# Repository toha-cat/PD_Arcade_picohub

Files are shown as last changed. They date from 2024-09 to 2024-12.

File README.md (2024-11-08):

# PD Arcade picohub
=================================

Firmware for Raspberry Pi Pico for use in Hatsune Miku Project DIVA Arcade Future Tone DIY-arcade controller 

Creates two USB-CDC and one HID devices:
- UART-bridge for connection [LKP](https://github.com/Project-Alpaca/LKP)-slider with [LKP-Serial](https://github.com/Project-Alpaca/LKP-FW) firmware.
- virtual COM-port that receives the commands for controlling the LEDs. Works in conjunction with the [PD-Arcade-Lights plugin](https://github.com/steelpuxnastik/PD-Arcade-Lights)
- HID-Gamepad for 5 buttons.

Example of PCB and it's description in [PCB folder](/PCB)

## Raspberry Pi Pico pin mapping
------------------------

| Raspberry Pi Pico GPIO | Function |
|---|---|
| 			**[LKP](https://github.com/Project-Alpaca/LKP)-slider connection**				|
| GPIO16 (Pin 21) | UART0 TX |
| GPIO17 (Pin 22) | UART0 RX |
| **LEDs** |
| GPIO2 (Pin 4) | BTN4 Circle LED (Circle) |
| GPIO3 (Pin 5) | BTN3 Cross LED (Cross) |
| GPIO4 (Pin 6) | BTN2 Square LED (Square) |
| GPIO5 (Pin 7) | BTN1 Triangle LED (Triangle) |
| GPIO6 (Pin 9) | R LINE B (RGB LED strip)|
| GPIO7 (Pin 10) | R LINE R (RGB LED strip)|
| GPIO8 (Pin 11) | R LINE G (RGB LED strip)|
| GPIO9 (Pin 12) | L LINE B (RGB LED strip)|
| GPIO10 (Pin 14) | L LINE R (RGB LED strip)|
| GPIO11 (Pin 15) | L LINE G (RGB LED strip)|
| GPIO15 (Pin 20) | LED-strip brightness PWM signal source|
| **Controls**	 			|
| GPIO18 (Pin 24) |  BTN 1 Triangle (Triangle) |
| GPIO19 (Pin 25) |  BTN 2 Square (Square) |
| GPIO20 (Pin 26) |  BTN 3 Cross (Cross) |
| GPIO21 (Pin 27) |  BTN 4 Circle (Circle) |
| GPIO22 (Pin 29) |  BTN 5 (Start)  |

## Disclaimer
----------

This software is provided without warranty, according to the MIT License, and should therefore not be used where it may endanger life, financial stakes, or cause discomfort and inconvenience to others.

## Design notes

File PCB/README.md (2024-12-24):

# PD Arcade picohub PCB
=================================
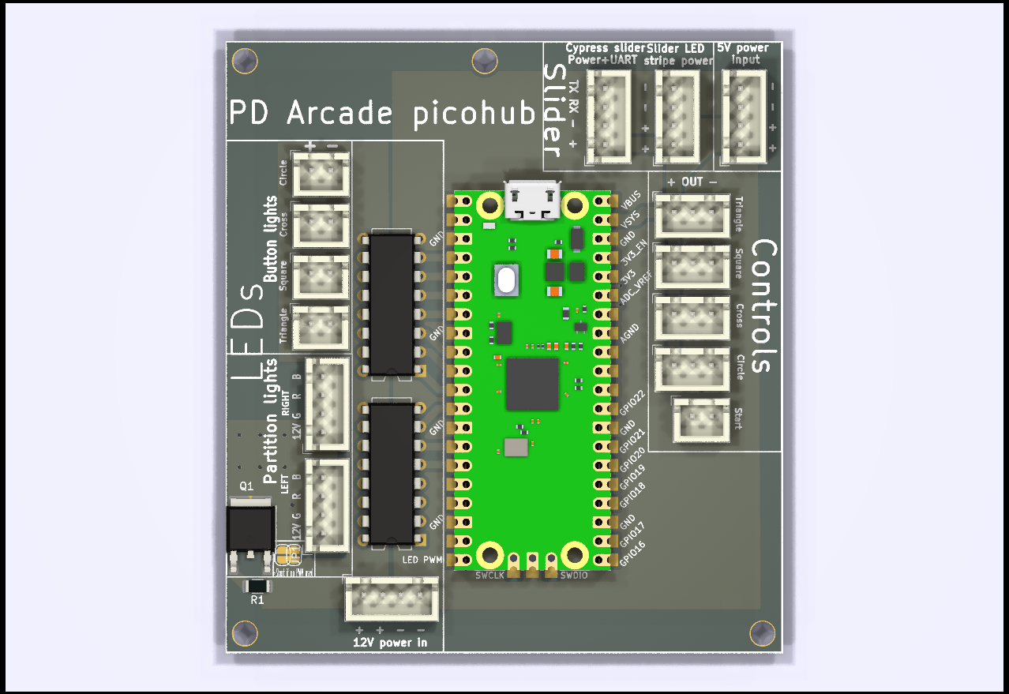
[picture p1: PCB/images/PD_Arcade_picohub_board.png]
PCB

## Parts list
- PCB: 1x `PD_Arcade_picohub_board` **1.6mm thickness** (KiCad 7.99+ (7.99.0-697-g4d05bd62da), release build required for exporting Gerber files or take Gerber files archive in `PCB/gerber/PD_Arcade_picohub_board.zip`)
  - U1: `Raspberry Pi Pico` board
  - U2, U3: 2x `ULN2003` transistor assembly
  - U4: `TXS0108EPW` bi-directional level-shifter *(used for connection [SHINSANWASWITCH](https://github.com/steelpuxnastik/SHINSANWASWITCH) optical switches as main buttons and [LKP](https://github.com/Project-Alpaca/LKP) slider. Those components are basically uses 5v power supply, that is why it needs level shifter to connect to Raspberry Pi Pico that uses 3.3v signal level. There are possible other configurations of those components and in case of their 3.3v power supply you can exclude `TXS0108EPW` and connect them directly to Raspberry Pi Pico pins bypassing level shifter)*
  - C1, C2: `0.1uf` 0603 SMD condenser *(used for level shifter)*
- Parts for PWM brightness control (short jumpers if no PWM used, **brightness control will not work**):
  - Q1: `IRFR9024N` P-channel MOSFET
  - Q2: `AO3404A` N-channel MOSFET
  - R1: `1k` 1206 SMD resistor
  - R2: `10k` 1206 SMD resistor
- connectors:
  - 2x DIP-16 panel for `ULN2003`
  - 5x `JST XH-02` male connector
  - 4x `JST XH-03` male connector *(used for connection [SHINSANWASWITCH](https://github.com/steelpuxnastik/SHINSANWASWITCH) optical switches for main buttons. It's an active component, so it uses 3 wires. If you use passive switches - you can change to `JST XH-02` and connect it directly to Raspberry Pi Pico pins bypassing level shifter)*
  - 6x `JST XH-04` male connector
  - female 2.54 single row headset for `Raspberry Pi Pico`
  
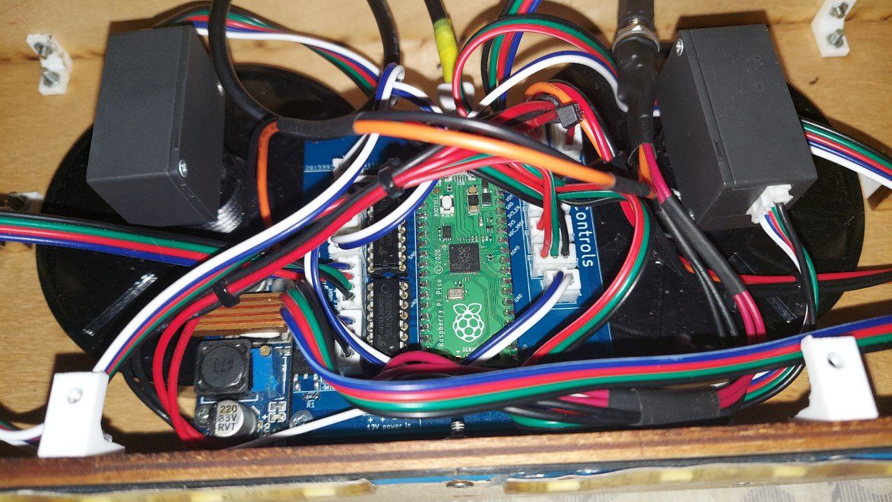
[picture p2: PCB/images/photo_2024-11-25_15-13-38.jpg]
PCB assembled


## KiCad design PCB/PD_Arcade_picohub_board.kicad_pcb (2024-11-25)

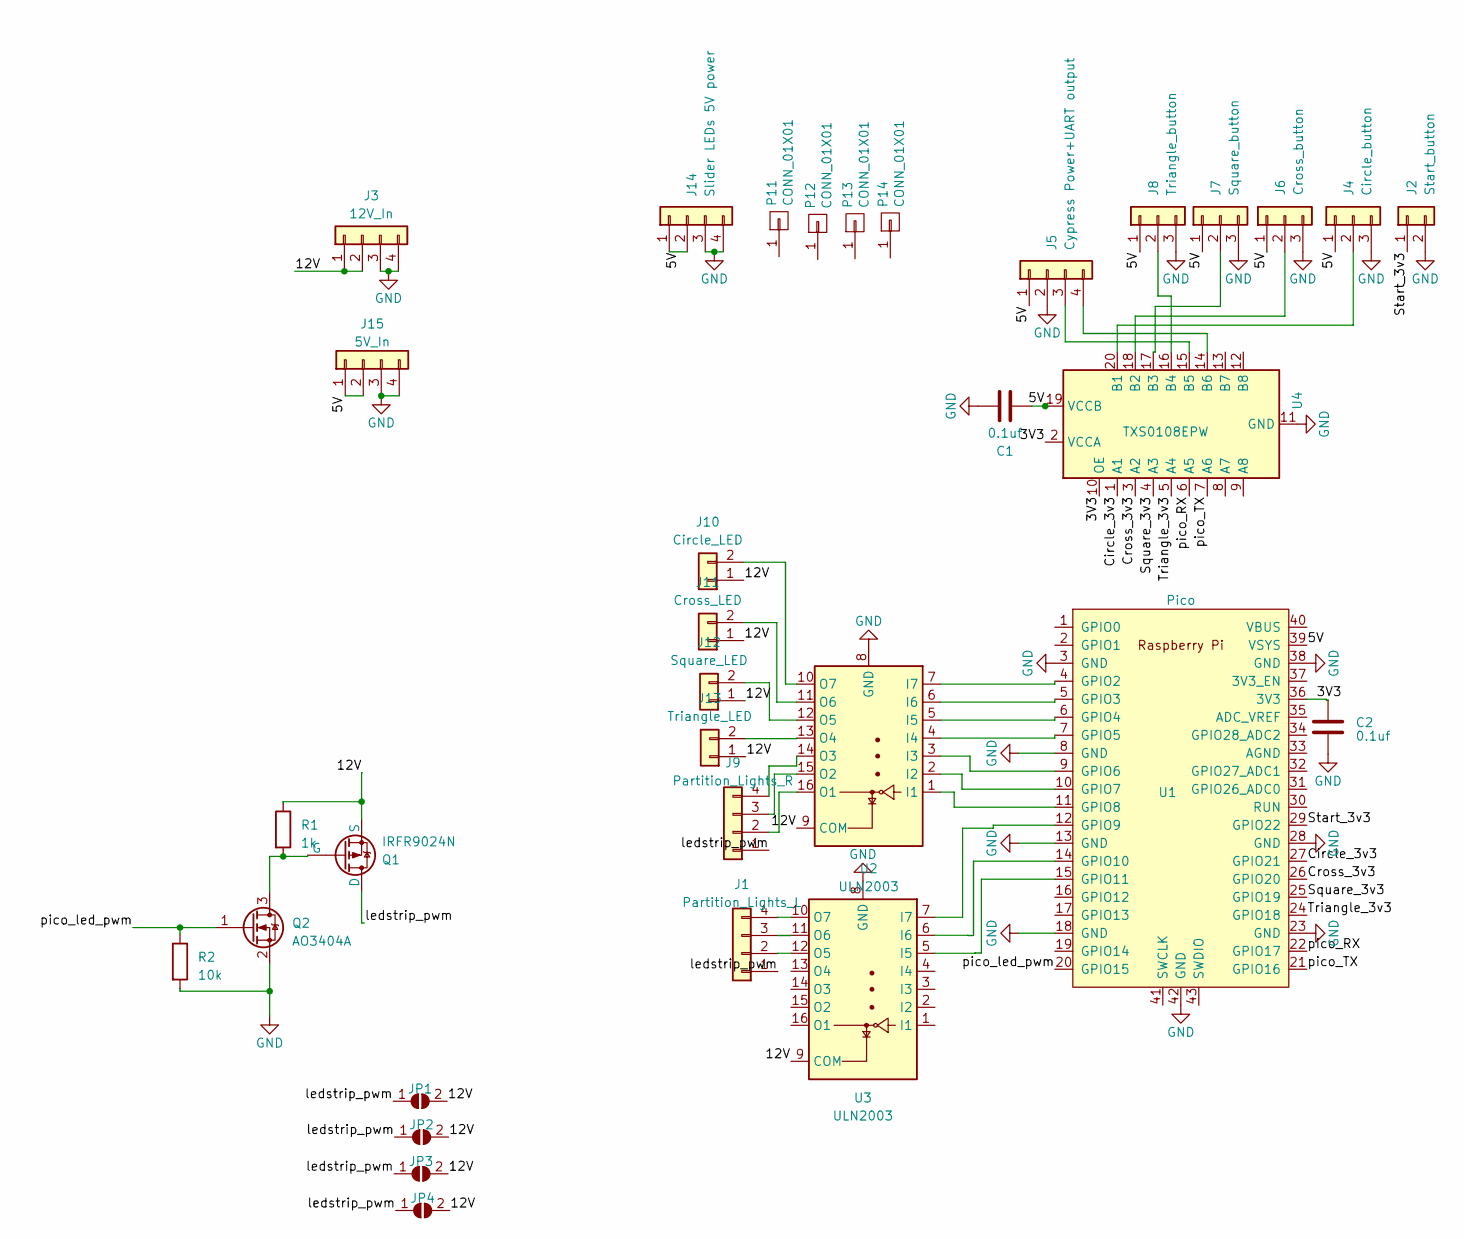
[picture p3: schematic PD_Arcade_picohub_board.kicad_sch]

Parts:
C1, C2: 0.1uf; C_0805_2012Metric
J1: Partition_Lights_L; JST_XH_B4B-XH-A_1x04_P2.50mm_Vertical
J2: Start_button; JST_XH_B2B-XH-A_1x02_P2.50mm_Vertical
J3: 12V_In; JST_XH_B4B-XH-A_1x04_P2.50mm_Vertical
J4: Circle_button; JST_XH_B3B-XH-A_1x03_P2.50mm_Vertical
J5: Cypress Power+UART output; JST_XH_B4B-XH-A_1x04_P2.50mm_Vertical
J6: Cross_button; JST_XH_B3B-XH-A_1x03_P2.50mm_Vertical
J7: Square_button; JST_XH_B3B-XH-A_1x03_P2.50mm_Vertical
J8: Triangle_button; JST_XH_B3B-XH-A_1x03_P2.50mm_Vertical
J9: Partition_Lights_R; JST_XH_B4B-XH-A_1x04_P2.50mm_Vertical
J10: Circle_LED; JST_XH_B2B-XH-A_1x02_P2.50mm_Vertical
J11: Cross_LED; JST_XH_B2B-XH-A_1x02_P2.50mm_Vertical
J12: Square_LED; JST_XH_B2B-XH-A_1x02_P2.50mm_Vertical
J13: Triangle_LED; JST_XH_B2B-XH-A_1x02_P2.50mm_Vertical
J14: Slider LEDs 5V power; JST_XH_B4B-XH-A_1x04_P2.50mm_Vertical
J15: 5V_In; JST_XH_B4B-XH-A_1x04_P2.50mm_Vertical
JP1, JP2, JP3, JP4: SolderJumper_2_Open; SolderJumper-2_P1.3mm_Open_RoundedPad1.0x1.5mm
P11, P12, P13, P14: CONN_01X01; MountingHole_3.2mm_M3_Pad
Q1: IRFR9024N; TO-252-2
Q2: AO3404A; SOT-23
R1: 1k; R_1206_3216Metric
R2: 10k; R_1206_3216Metric
U1: Pico; RPi_Pico_SMD_TH
U2, U3: ULN2003; DIP-16_W7.62mm
U4: TXS0108EPW; TSSOP-20_4.4x6.5mm_P0.65mm

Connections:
/3V3: C2.1, U1.36 (3V3), U4.2 (VCCA), U4.10 (OE)
/5V: C1.2, J4.1, J5.1, J6.1, J7.1, J8.1, J14.1, J14.2, J15.1, J15.2, U1.39 (VSYS), U4.19 (VCCB)
/12V: J3.1, J3.2, J10.1, J11.1, J12.1, J13.1, JP1.2 (B), JP2.2 (B), JP3.2 (B), JP4.2 (B), Q1.3 (S), R1.1, U2.9 (COM), U3.9 (COM)
/Circle_3v3: U1.27 (GPIO21), U4.1 (A1)
/Cross_3v3: U1.26 (GPIO20), U4.3 (A2)
/Square_3v3: U1.25 (GPIO19), U4.4 (A3)
/Start_3v3: J2.1, U1.29 (GPIO22)
/Triangle_3v3: U1.24 (GPIO18), U4.5 (A4)
/ledstrip_pwm: J1.1, J9.1, JP1.1 (A), JP2.1 (A), JP3.1 (A), JP4.1 (A), Q1.2 (D)
/pico_RX: U1.22 (GPIO17), U4.6 (A5)
/pico_TX: U1.21 (GPIO16), U4.7 (A6)
/pico_led_pwm: Q2.1 (G), R2.1, U1.20 (GPIO15)
GND: C1.1, C2.2, J2.2, J3.3, J3.4, J4.3, J5.2, J6.3, J7.3, J8.3, J14.3, J14.4, J15.3, J15.4, Q2.2 (S), R2.2, U1.3 (GND), U1.8 (GND), U1.13 (GND), U1.18 (GND), U1.23 (GND), U1.28 (GND), U1.38 (GND), U1.42 (GND), U2.8 (GND), U3.8 (GND), U4.11 (GND)
unnamed: J1.2, U3.12 (O5)
unnamed: J1.3, U3.11 (O6)
unnamed: J1.4, U3.10 (O7)
unnamed: J4.2, U4.20 (B1)
unnamed: J5.3, U4.15 (B5)
unnamed: J5.4, U4.14 (B6)
unnamed: J6.2, U4.18 (B2)
unnamed: J7.2, U4.17 (B3)
unnamed: J8.2, U4.16 (B4)
unnamed: J9.2, U2.16 (O1)
unnamed: J9.3, U2.15 (O2)
unnamed: J9.4, U2.14 (O3)
unnamed: J10.2, U2.10 (O7)
unnamed: J11.2, U2.11 (O6)
unnamed: J12.2, U2.12 (O5)
unnamed: J13.2, U2.13 (O4)
unnamed: Q1.1 (G), Q2.3 (D), R1.2
unnamed: U1.4 (GPIO2), U2.7 (I7)
unnamed: U1.5 (GPIO3), U2.6 (I6)
unnamed: U1.6 (GPIO4), U2.5 (I5)
unnamed: U1.7 (GPIO5), U2.4 (I4)
unnamed: U1.9 (GPIO6), U2.3 (I3)
unnamed: U1.10 (GPIO7), U2.2 (I2)
unnamed: U1.11 (GPIO8), U2.1 (I1)
unnamed: U1.12 (GPIO9), U3.7 (I7)
unnamed: U1.14 (GPIO10), U3.6 (I6)
unnamed: U1.15 (GPIO11), U3.5 (I5)

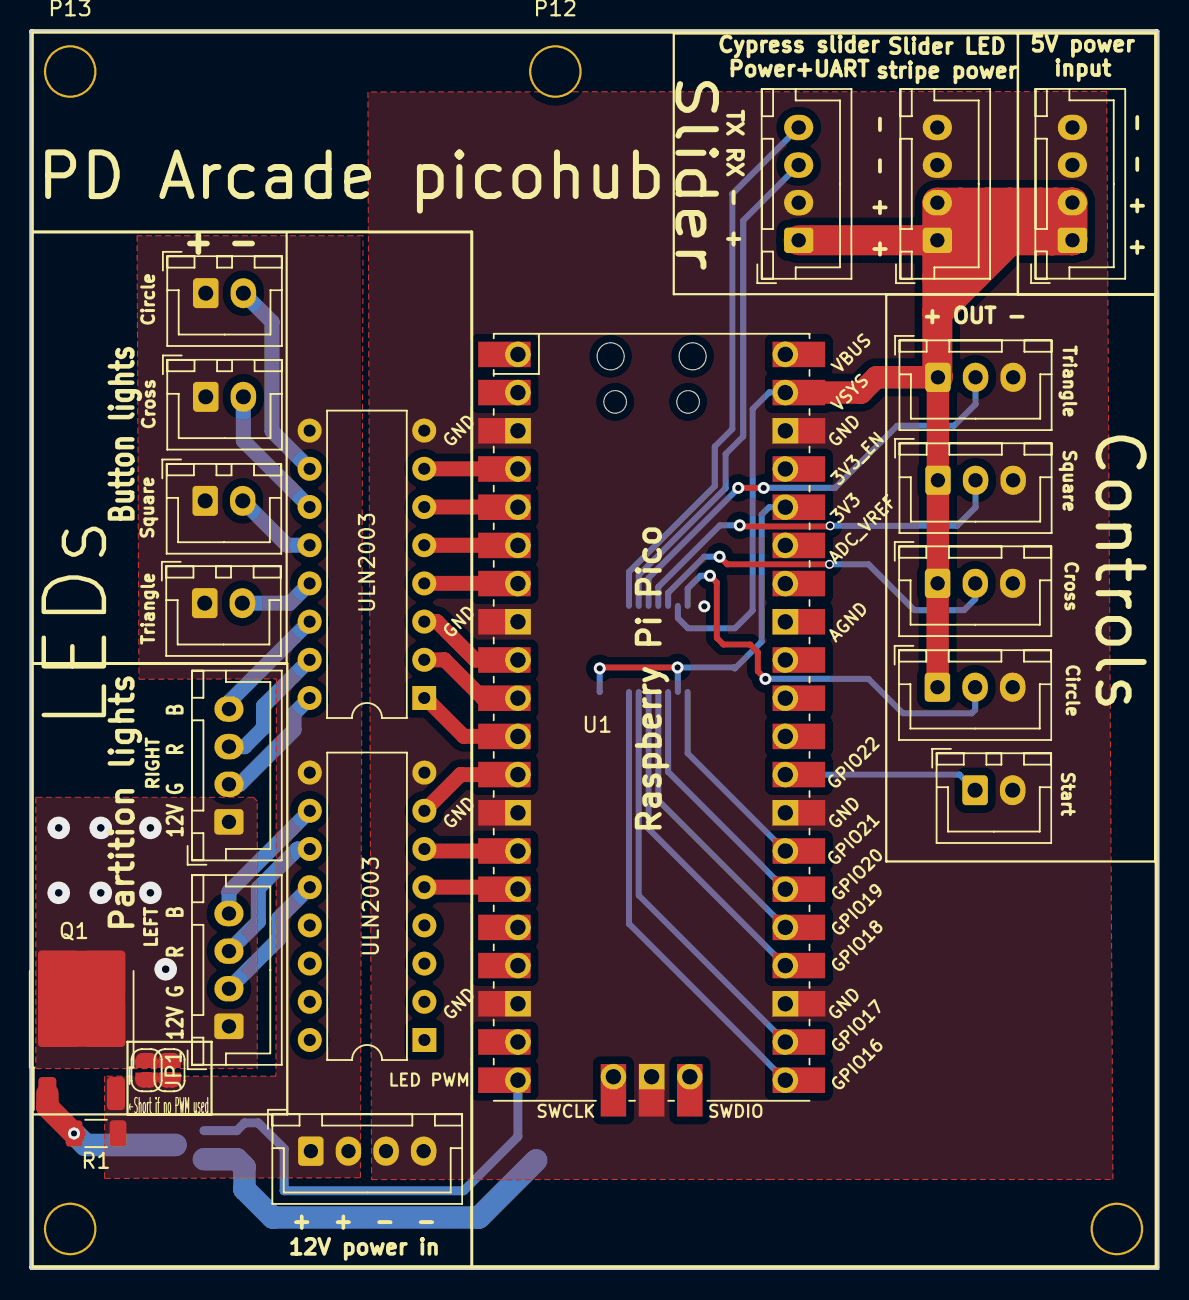
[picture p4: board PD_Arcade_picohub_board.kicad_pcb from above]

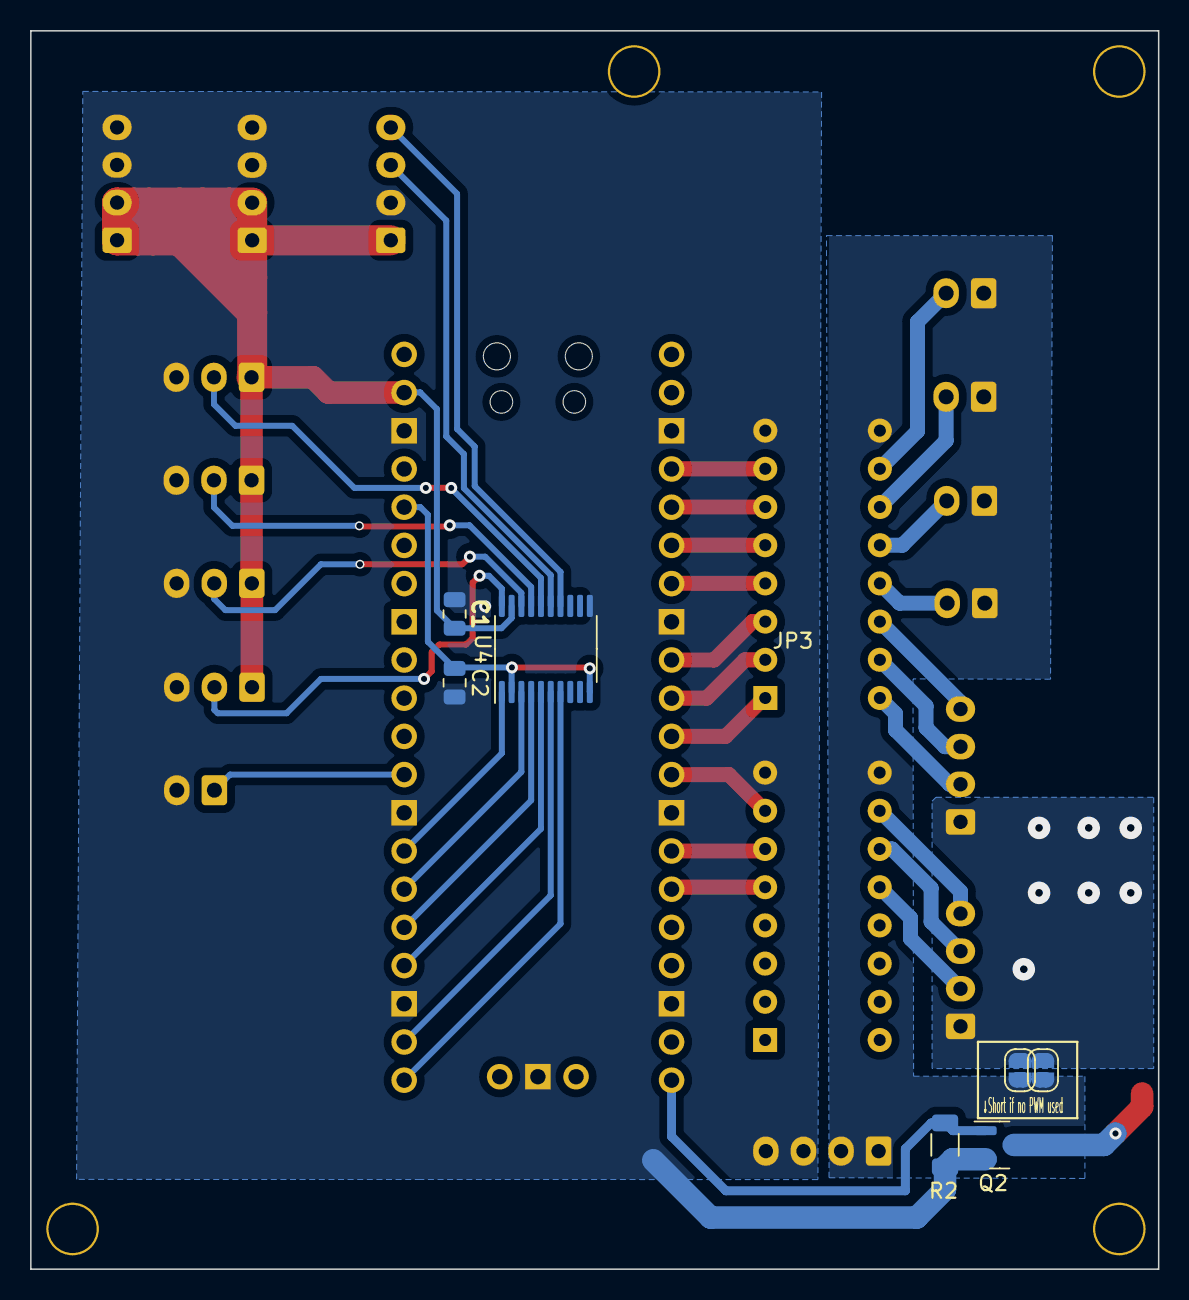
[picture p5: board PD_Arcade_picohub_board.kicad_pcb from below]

Board: 2 copper layers, 75.0 x 82.3 mm, 33 parts (7 on the bottom side), 40 nets.

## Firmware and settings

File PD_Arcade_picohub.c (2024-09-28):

#include <pico/multicore.h>
#include <pico/stdlib.h>
#include <tusb.h>

#include "uart-process.h"
#include "usb-process.h"
#include "leds.h"
#include "usb-gamepad.h"


int main(void)
{
	usbd_serial_init();

	// init UART
	initUartData();
	initUartHardware();

	// init all led gpio
	initLedGpios();
	// init btns gpio
	initGamepadGpios();

	// processing usb-cdc to second core
	multicore_launch_core1(usbProcessing);

	while (1) {
		uartUpdateCfg();
		uartWriteBytes();
	}

	return 0;
}

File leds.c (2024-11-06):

#include "leds.h"
#include "hardware/pwm.h"
#include "hardware/gpio.h"

// GPIO number (not pins)
#define ARCADE_LED_BTN1 5  // BUTTON LED TRIANGLE
#define ARCADE_LED_BTN2 4  // BUTTON LED SQUARE
#define ARCADE_LED_BTN3 3  // BUTTON LED CROSS
#define ARCADE_LED_BTN4 2  // BUTTON LED CIRCLE
#define ARCADE_LED_R1 10  // LEFT PARTITION LED RED
#define ARCADE_LED_G1 11  // LEFT PARTITION LED GREEN
#define ARCADE_LED_B1 9  // LEFT PARTITION LED BLUE
#define ARCADE_LED_R2 7  // RIGHT PARTITION LED RED
#define ARCADE_LED_G2 8 // RIGHT PARTITION LED GREEN
#define ARCADE_LED_B2 6 // RIGHT PARTITION LED BLUE

#define ARCADE_LED_PWM_PIN 15 // PWM out pin for brightness
#define ARCADE_LED_PWM_WRAP 12500

#define ARCADE_COUNT_LED 10
uint arcadeLeds[ARCADE_COUNT_LED] = {
	ARCADE_LED_BTN1,
	ARCADE_LED_BTN2,
	ARCADE_LED_BTN3,
	ARCADE_LED_BTN4,
	ARCADE_LED_R1,
	ARCADE_LED_G1,
	ARCADE_LED_B1,
	ARCADE_LED_R2,
	ARCADE_LED_G2,
	ARCADE_LED_B2
};

#define LED_CONN_STAT 25

inline uint readBite(uint data, uint nBite)
{
	return (data >> nBite) & 0b00000001;
}

void ledSlidesUpdate(uint8_t inData) 
{
    gpio_put(ARCADE_LED_R1, readBite(inData, 0));
    gpio_put(ARCADE_LED_G1, readBite(inData, 1));
    gpio_put(ARCADE_LED_B1, readBite(inData, 2));

    gpio_put(ARCADE_LED_R2, readBite(inData, 3));
    gpio_put(ARCADE_LED_G2, readBite(inData, 4));
    gpio_put(ARCADE_LED_B2, readBite(inData, 5));
}

void ledBtnsUpdate(uint8_t inData) 
{
    gpio_put(ARCADE_LED_BTN1, readBite(inData, 0));
    gpio_put(ARCADE_LED_BTN2, readBite(inData, 1));
    gpio_put(ARCADE_LED_BTN3, readBite(inData, 2));
    gpio_put(ARCADE_LED_BTN4, readBite(inData, 3));
}

void ledBrightnessUpdate(uint8_t inData) 
{
	const int maxInputValue = 50;
    uint16_t levelPer = inData & 0b00111111;

	if(levelPer > maxInputValue){
		levelPer = maxInputValue;
	}

	uint slice_num = pwm_gpio_to_slice_num(ARCADE_LED_PWM_PIN);
    uint chan = pwm_gpio_to_channel(ARCADE_LED_PWM_PIN);

	uint16_t level = levelPer * ARCADE_LED_PWM_WRAP / maxInputValue;
    pwm_set_chan_level(slice_num, chan, level);

}

void ledInsertData(uint8_t *data, int32_t len)
{
    for (uint i = 0; i < len; i++)
	{
		uint8_t typeData = data[i] & 0b11000000;
		switch(typeData){
		case 0b00000000:
			ledSlidesUpdate(data[i]);
			break;
		case 0b11000000:
			ledBtnsUpdate(data[i]);
			break;
		case 0b01000000:
			// set brightness
			ledBrightnessUpdate(data[i]);
			break;
		}
	}
}

void ledSetStatus(int stat)
{
    gpio_put(LED_CONN_STAT, stat);
}

void initLedPwm(void) {
    // set GPIO to PWM
    gpio_set_function(ARCADE_LED_PWM_PIN, GPIO_FUNC_PWM);
    
    // get slice/channel for GPIO
    uint slice_num = pwm_gpio_to_slice_num(ARCADE_LED_PWM_PIN);
    uint chan = pwm_gpio_to_channel(ARCADE_LED_PWM_PIN);
    
    // setup PWM
    pwm_config config = pwm_get_default_config();
    pwm_config_set_wrap(&config,  ARCADE_LED_PWM_WRAP);
    pwm_init(slice_num, &config, true);
    
    // set the initial level to 100%
    pwm_set_chan_level(slice_num, chan,  ARCADE_LED_PWM_WRAP);
}

void initLedGpios()
{
	gpio_init(LED_CONN_STAT);
	gpio_set_dir(LED_CONN_STAT, GPIO_OUT);

	for (int i = 0; i < ARCADE_COUNT_LED; i++)
	{
		gpio_init(arcadeLeds[i]);
		gpio_set_dir(arcadeLeds[i], GPIO_OUT);
	}

	initLedPwm();
}

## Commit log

2024-08-25 Fix getting led data. Code cleanup
    [PD_Arcade_picohub.c, usb-process.c]
2024-08-25 Set uart inst
2024-09-27 LED control protocol version 2
2024-09-30 timer replacement
2024-11-05 Update README.md
    According to the PCB
2024-11-06 addition PCB that used in project
    [PD_Arcade_picohub_board.kicad_pcb, PD_Arcade_picohub_board.kicad_sch]
2024-11-06 PCB readme
    [PD_Arcade_picohub_board.kicad_pcb, PD_Arcade_picohub_board.kicad_sch]
2024-11-07 README.md and PCB update
    [PD_Arcade_picohub_board.kicad_pcb]
2024-11-08 README.md update
    [PD_Arcade_picohub_board.kicad_pcb]
2024-11-25 R1 fix to 1k
    10k do not work
    [PD_Arcade_picohub_board.kicad_pcb, PD_Arcade_picohub_board.kicad_sch]
2024-11-25 assembled PCB
2024-12-10 change names of devices
